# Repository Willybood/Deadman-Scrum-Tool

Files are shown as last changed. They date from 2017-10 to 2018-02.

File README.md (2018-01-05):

# The Deadman Scrum Tool
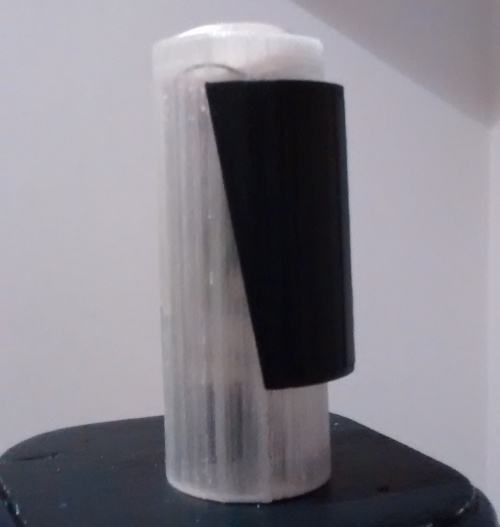
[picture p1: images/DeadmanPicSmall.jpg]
Deadman Scrum Tool


This project is for a deadman's switch that is passed around to different team members during a stand up. The user pushes a button on the device, then after 90 seconds, it begins buzzing to tell the user to end.
## About the Deadman
While introducing Scrum to a new team, we quickly had issues with team members wanting to speak over each other during stand ups and extend the meeting beyond the 15 minutes. During one of the early retrospectives someone suggested a handheld device that lets people know if they've been talking for too long, and using left over parts and a public 3D printer I began prototyping. After introducing it, the stand ups have been smoother.
## How does it work
1. Turn on the power switch on the bottom. The device will boot up and a green light will come on.
2. Grip the device in your hand so the large switch is held down. The light will begin to slowly flash red. During which you tell the rest of the team the standard stand up procedure of what you've worked on, what you'll be working on, and what's blocking you.
3. The flashing will gradually increase up until your 90 seconds are up, after which it will begin to play 'Shave and a haircut' until the switch is released.
4. After you're finished, release the grip and hand it to the next person.
5. And after the team is finished, turn off the switch on the bottom and the light will go out.
## Software
The device runs on an Adafruit Trinket. The .ino file is available to upload [here](/code/deadman/deadman.ino?raw=true).
## Hardware
The device consists of a set of electronic components inserted into three 3D printed parts.
### 3D printed parts
The device consists of three prints:
* [caseHalfLeft.stl](https://github.com/Willybood/Deadman-Scrum-Tool/blob/master/model%20files/caseHalfLeft.stl) and [caseHalfRight.stl](https://github.com/Willybood/Deadman-Scrum-Tool/blob/master/model%20files/caseHalfRight.stl). These are printed and then can be pushed in place with no glue needed.
* [holder.stl](https://github.com/Willybood/Deadman-Scrum-Tool/blob/master/model%20files/holder.stl). This is the component that is gripped to close the switch. After printing it, it can be placed into the holes on the side of the case.
### Components
* [Adafruit Trinket](https://www.amazon.co.uk/gp/product/B00M40XTI4/ref=oh_aui_detailpage_o05_s00?ie=UTF8&psc=1)
* [Hinge lever switch](https://www.amazon.co.uk/gp/product/B00M1ZTO2C/ref=oh_aui_detailpage_o04_s01?ie=UTF8&psc=1)
* [AAA battery case holder](https://www.amazon.co.uk/gp/product/B00H8T6J3S/ref=oh_aui_detailpage_o04_s00?ie=UTF8&psc=1)
* [AAA form factor li-ion battery](https://www.amazon.co.uk/gp/product/B016CT546C/ref=oh_aui_detailpage_o04_s00?ie=UTF8&psc=1)
* [Two position switch](https://www.amazon.co.uk/gp/product/B007QAJMHO/ref=oh_aui_detailpage_o03_s00?ie=UTF8&psc=1) as well as some small screws and bolts to hold it into place.
* [Low profile piezo sounder](https://www.maplin.co.uk/p/30v-very-low-profile-piezo-sounder-4mm-ku57m)
* [RGB LED board](https://www.amazon.co.uk/kwmobile-RGB-LED-module-Arduino/dp/B01N248IOR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), you can use a three color LED and a pair of resistors, but I had one of these lying around.

I used some [gorilla glue](https://www.amazon.co.uk/gp/product/B009NQQJFC/ref=oh_aui_detailpage_o01_s00?ie=UTF8&psc=1) to hold some of the components in place.
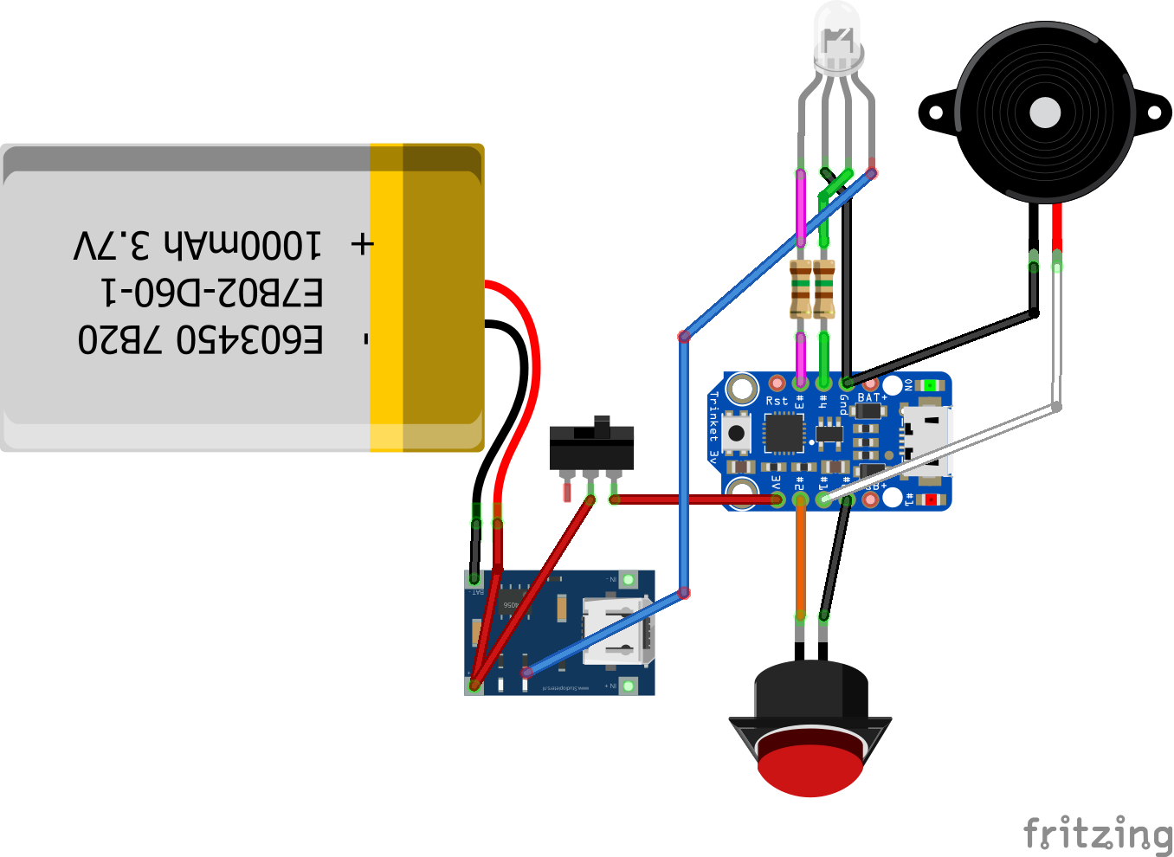
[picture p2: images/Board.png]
Fritzing diagram

<p align="center"><i>Fritzing diagram describing the components wiring</i></p>

## Special thanks
* I'd like to thank my team for coming up with the idea and trying out my prototypes.
* One inspiration for this came from the [Scrumato](https://github.com/platisd/scrumtato) stand up tool, which I would have built instead if only I had the components for it lying around around. It looks like a good tool, and I'm sure it would have worked too.

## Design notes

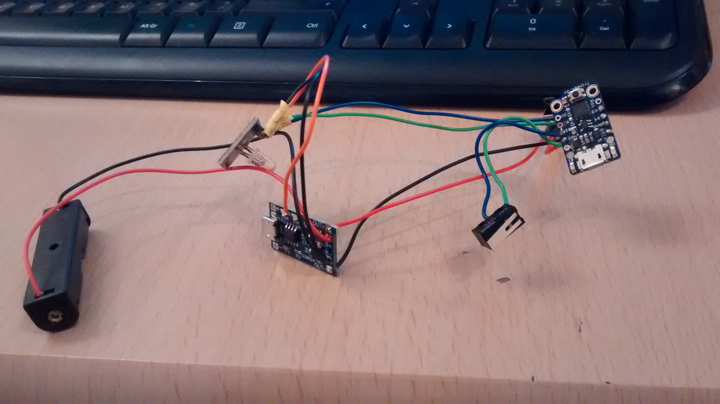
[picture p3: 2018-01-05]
images/Picture of circuitry.jpg

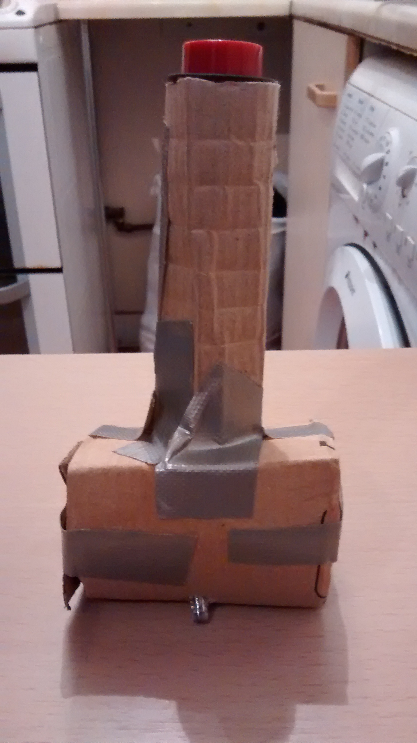
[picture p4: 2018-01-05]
images/First Cardboard prototype.jpg

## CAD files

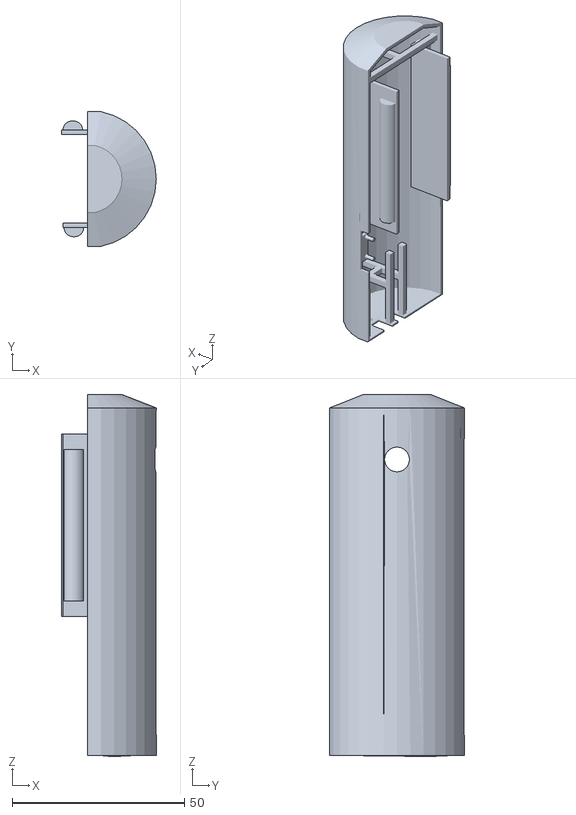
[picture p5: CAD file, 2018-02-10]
model files/caseHalfLeft.stl
27.5 x 39.1 x 105.2

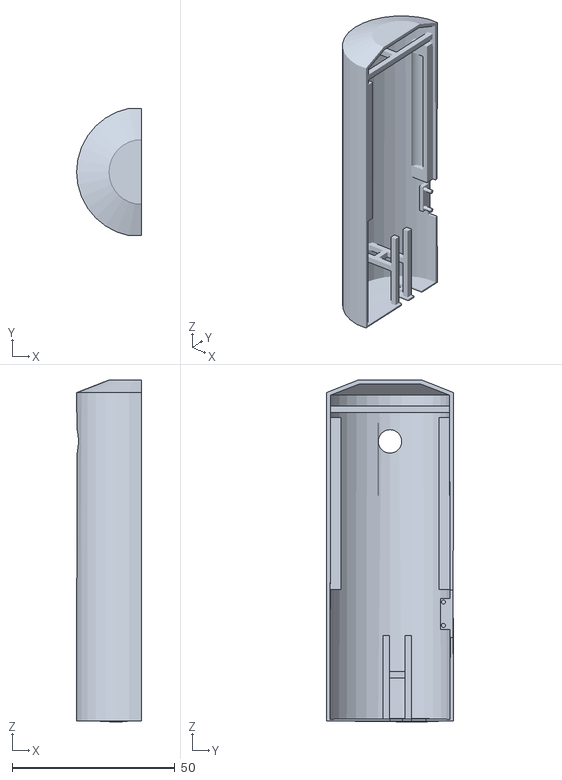
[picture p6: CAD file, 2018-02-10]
model files/caseHalfRight.stl
19.9 x 39.1 x 105.2

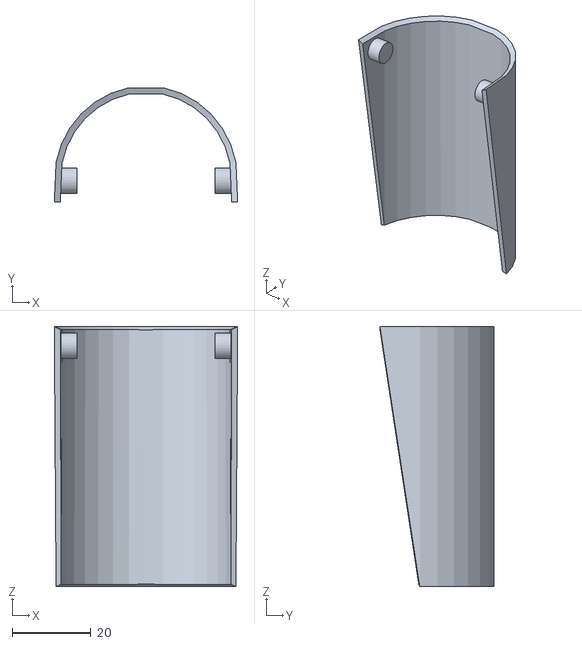
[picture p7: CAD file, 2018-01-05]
model files/holder.stl
46.5 x 29.0 x 66.0

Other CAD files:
model files/case.blend

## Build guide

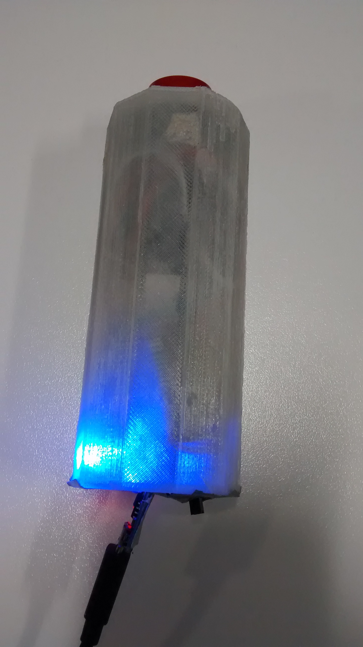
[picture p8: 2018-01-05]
images/Second 3D printed prototype.jpg

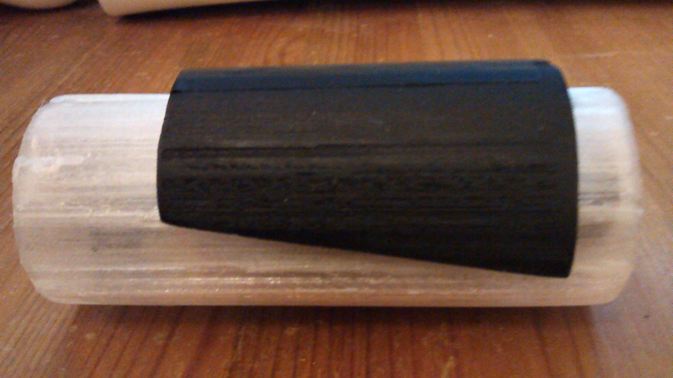
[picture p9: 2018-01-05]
images/Third 3D printed prototype.jpg

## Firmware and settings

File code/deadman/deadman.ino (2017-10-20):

/*
 * When the button is pushed a timer counts down.
 * When it reaches a set amount, it starts buzzing until the button is depressed.
 * Piezo buzzer code is taken from https://www.arduino.cc/en/Tutorial/ToneMelody?from=Tutorial.Tone
 */

#include "Timer.h"
#include "ttone.h"

// Defines for the serial port, disables it for all non-prototype hardware
#if defined(__AVR_ATmega168__) || defined(__AVR_ATmega328P__)
#define serialPrint(x) Serial.println(x)
#define serialBegin(x) Serial.begin(x)
#else
#define serialPrint(x)
#define serialBegin(x)
#endif

const int BUZZER_PIN = 1; // Output pin for the buzzer, required to be pin 1 for the ttone library
const int BUTTON_PIN = 0; // Input pin for the button to be held down
const int BUTTON_V_PIN = 2; // Input pin for the button, provides the voltage needed
const int RED_LED_PIN = 3; // Output pins for the LEDs
const int GREEN_LED_PIN = 4; // Output pins for the LEDs

const int SECONDS_TO_WAIT = 90UL; // The amount of time to wait before setting off the alarm
const int TIME_BETWEEN_BUZZES = 3000; // The time between tones played

const int NUM_OF_OSC_SEGMENTS = 9; // The number of segments of oscillation of the LED to make as the user gets closer to their limit
int currentOscSegment = 0; // The current oscillating segment

// notes in the melody:
int melody[] = {
  C4, G3, G3, A3, G3, 0, B3, C4
};
const int NUM_OF_NOTES = 8;

unsigned long millisWhenPushed = 0; // The value of millis (milliseconds since boot) when the button is pushed

const long LONG_OSC_PERIOD = 1000L; // longest time in ms to flash the LED. Other variants are fractions of this number

// note durations: 4 = quarter note, 8 = eighth note, etc.:
int noteDurations[] = {
  4, 8, 8, 4, 4, 4, 4, 4
};

// Events used by the timer library
// By default are set to 'MAX_NUMBER_OF_EVENTS' so they cannot be set or unset accidentally
int buzzerEvent = MAX_NUMBER_OF_EVENTS; // The event that controls the buzzing
int timerEvent = MAX_NUMBER_OF_EVENTS; // The event that counts down the timer
int ledOscillations = MAX_NUMBER_OF_EVENTS; // The event that controls the LED oscillations

Timer timer; // Third party object type that controls the timing

bool countingDown = false;

// Function run once at startup
void setup() {
  serialPrint(("Entering %s", __FUNCTION__));
  serialBegin(9600);
  
  pinMode(BUTTON_PIN, INPUT);
  digitalWrite(BUTTON_PIN, INPUT_PULLUP);
  pinMode(BUTTON_V_PIN, OUTPUT);
  digitalWrite(BUTTON_V_PIN, LOW);

  pinMode(RED_LED_PIN, OUTPUT);
  pinMode(GREEN_LED_PIN, OUTPUT);

  pinMode(BUZZER_PIN, OUTPUT);
  
  serialPrint("Program started");
}

// Plays the tone
void playTone() {
  serialPrint(("Entering %s", __FUNCTION__));
  // iterate over the notes of the melody:
  for (int thisNote = 0; thisNote < NUM_OF_NOTES; thisNote++) {

    // to calculate the note duration, take one second divided by the note type.
    //e.g. quarter note = 1000 / 4, eighth note = 1000/8, etc.
    int noteDuration = 1000 / noteDurations[thisNote];
    trinketTone(melody[thisNote], noteDuration);

    // to distinguish the notes, set a minimum time between them.
    // the note's duration + 30% seems to work well:
    const int pauseBetweenNotes = noteDuration * 1.30;
    delay(pauseBetweenNotes);
  }
}

// Starts the buzzing
void startBuzzing() {
  serialPrint(("Entering %s", __FUNCTION__));
  timer.stop(ledOscillations);
  digitalWrite(RED_LED_PIN, HIGH);
  buzzerEvent = timer.every(TIME_BETWEEN_BUZZES, playTone);
}

// Stops the buzzing
void stopBuzzing() {
  serialPrint(("Entering %s", __FUNCTION__));
  timer.stop(buzzerEvent);
}

// Starts the countdown
void startCountdown() {
  serialPrint(("Entering %s", __FUNCTION__));
  const unsigned long timeToWait = SECONDS_TO_WAIT * 1000UL;
  timerEvent = timer.after(timeToWait, startBuzzing);
}

// Stops the countdown
void stopCountdown() {
  serialPrint(("Entering %s", __FUNCTION__));
  timer.stop(timerEvent);
}

// Sets the pulsing of the LEDs.
// Gets faster as the user reaches their talking limit.
void updatePulsingLEDs() {
  for(int i = 1; i < NUM_OF_OSC_SEGMENTS; ++i) {
    const unsigned long millisSpent = millis() - millisWhenPushed; // The number of milliseconds ela[sed since the button was pushed.
    const unsigned long proportionOfWaitTime = ((unsigned long)SECONDS_TO_WAIT * 1000UL) / (unsigned long)NUM_OF_OSC_SEGMENTS;
    if((millisSpent < (proportionOfWaitTime * i)) && (millisSpent >= (proportionOfWaitTime * (i - 1)))) {
      if(currentOscSegment != i) {
        timer.stop(ledOscillations);
        ledOscillations = timer.oscillate(RED_LED_PIN, (LONG_OSC_PERIOD / (long)NUM_OF_OSC_SEGMENTS) * (NUM_OF_OSC_SEGMENTS - i), digitalRead(RED_LED_PIN));
      }
      currentOscSegment = i;
    }
  }
}

// Function run repeatedly
void loop() {
  timer.update();
  
  // read the state of the pushbutton value:
  int buttonState = digitalRead(BUTTON_PIN);

  // check if the pushbutton is pressed.
  if (buttonState == LOW) {
    if(false == countingDown) {
      startCountdown();
      millisWhenPushed = millis();
      currentOscSegment = 0;
      digitalWrite(RED_LED_PIN, HIGH); // Turn the LED pin on when first pushed.
    }
    digitalWrite(GREEN_LED_PIN, LOW);
    updatePulsingLEDs();
    countingDown = true;
  } else {
    if(true == countingDown) {
      stopBuzzing();
      stopCountdown();
    }
    digitalWrite(RED_LED_PIN, LOW);
    digitalWrite(GREEN_LED_PIN, HIGH);
    countingDown = false;
  }
}

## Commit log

2017-09-20 Have added a draft Fritzing and readied the code for the arduino mini pro.
    [Board.fzz]
2017-09-22 Have added a picture of the board for easy viewing.
2017-09-22 Have added theoretical code for piezzo buzzers.
    [deadman.ino]
2017-09-23 Have fixed some minor code cleanliness issues.
    [deadman.ino]
2017-09-23 Have added a debounce to work around the fact that I'm not using a pull down resistor on the button input.
2017-09-24 Have had to compromise some features for a couple of last minute issues during construction.
    [deadman.ino]
2017-09-26 Have fixed the issues relating to the button input and restored the lost features.
    [deadman.ino]
2017-09-27 Have put together a new version of the board.
    [Board.fzz]
2017-10-01 First draft of the case.
    [case.blend, caseHalf.stl]
2017-10-05 First version of the case to be 3d printed.
    [case.blend, caseHalf.stl]
2017-10-05 Have updated the 3D model based on an issue seen at the makerspace.
    [case.blend, caseHalf.stl]
2017-10-09 Have fixed issues coming off of first 3D printed attempt.
    [case.blend, caseHalf.stl, caseHalfLeft.stl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]
2017-10-14 Can now detect button pushes when the tune is playing.
2017-10-14 Have added LED oscillations when the button is pushed.
    [deadman.ino]
2017-10-15 Case with grip switch
    [HolderLeft.stl, HolderRight.stl, case.blend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]
2017-10-15 Have modded the holder to make it smaller.
    [HolderLeft.stl, HolderRight.stl, case.blend]
2017-10-17 The red LED flashes faster as the user reaches their talking limit.
2017-10-17 Have updated the fritzing based on my experiments.
    [Board.fzz]
2017-10-19 Have changed the buzzer in use.
    [Board.fzz, case.blend]
2017-10-20 Changes after debugging with the trinket.
    [Board.fzz]
2017-10-24 Updated the model after prototyping
    [HolderLeft.stl, HolderRight.stl, case.blend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]
2017-10-26 Added a board image
2017-12-09 New version after using it for a month
    [HolderLeft.stl, HolderRight.stl, case.blend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]
2017-12-09 Have merged the holder halves
    As an experiment.
    [HolderLeft.stl, HolderRight.stl, case.blend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]
2018-01-05 Cleaned up the folders and updated the readme
    [Board.fzz, HolderLeft.stl, HolderRight.stl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]
2018-02-10 Have explicitely added the required Timer library.
2018-02-10 Have added fasteners to hold some components in place
    [case.blend, caseHalfLeft.stl, caseHalfRight.stl]
